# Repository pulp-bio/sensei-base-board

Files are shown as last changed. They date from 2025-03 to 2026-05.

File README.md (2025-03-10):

# SENSEI Base Board

This repository contains the hardware design files for the **SENSEI Base Board**, a flexible and ultra-low-power platform designed for edge AI and signal processing applications. The SENSEI Base Board enables modular integration of external sensors and specialized extension boards, making it an ideal foundation for multi-domain applications and long-term deployments in various monitoring use cases.

## Overview

The **SENSEI Base Board** is designed for advanced edge processing with a focus on low-power operation and flexibility. It incorporates key components such as **GAP9** and **NRF5340**, enabling multi-protocol connectivity and efficient near-sensor computation for advanced feature extraction and data compression. The board is also equipped with a variety of sensor interfaces and external connectors to support a wide range of use cases.

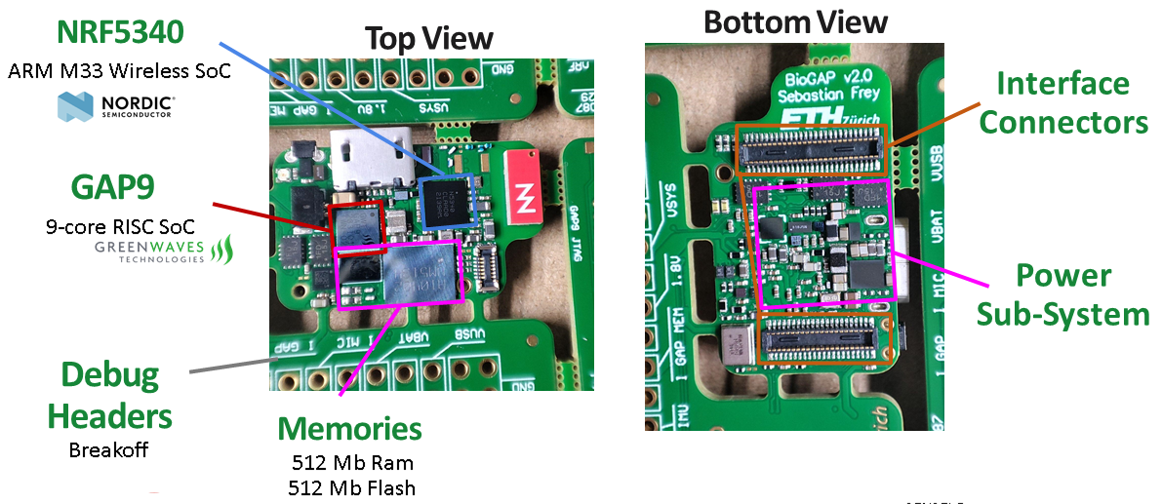
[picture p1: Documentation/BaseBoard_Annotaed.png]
Altium Screenshot


### Key Features
- **GAP9 SoC**:
  - 9-core RISC SoC with a fabric controller running up to 370 MHz.
  - 1536 kB L2 and 128 kB L1 on-chip memories.
  - Hardware acceleration via **NE16**.
  - External RAM (512Mbit) and Flash (512Mbit).
  
- **NRF5340 SoC**:
  - Multi-protocol Bluetooth Low Energy (BLE 5.4), IEEE 802.15.4, ANT, and 2.4GHz proprietary connectivity.
  - Dual-core Arm Cortex-M33 (128/64 MHz application processor and 64 MHz network processor).
  - 1 MB Flash and 512 KB RAM for the application processor, with external memory support.

## Changelog
A detailed changelog is available in the [Changelog.md](Changelog.md) file, which tracks all major updates and revisions to the board's design and documentation.

## Contributors
- **Sebastian Frey** ([sefrey@iis.ee.ethz.ch](mailto:sefrey@iis.ee.ethz.ch))
- **Philip Wiese** ([wiesep@iis.ee.ethz.ch](mailto:wiesep@iis.ee.ethz.ch))

## License
This repository makes use of the following licenses:
- for all *hardware*: Solderpad Hardware License Version 0.51
- for all *images*: Creative Commons Attribution 4.0 International
License][cc-by]

For further information have a look at the license files: `LICENSE.hw`, `LICENSE.images`

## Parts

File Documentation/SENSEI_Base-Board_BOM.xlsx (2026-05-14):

Designator | Comment | Quantity | Manufacturer
C1, C2 | GRM035R60J475ME15D | 2
C3, C4 | CBR02C200F5GAC | 2
C5, C6, C7, C12, C18, C20, C22, C23, C47, C51, C52, C53, C54, C57, C64, C65, C69, C70, C74, C84, C92, C95, C97 | CL03A105KP3NSNC | 23
C8, C10, C24, C49, C55, C71, C72 | C1005X5R0J475K050BC | 7
C9, C11, C19, C21, C25, C26, C27, C28, C29, C30, C31, C33, C34, C35, C36, C37, C38, C39, C48, C50, C56, C58, C60, C61, C73, C75, C76, C77, C78, C79, C80, C81, C82, C85, C86, C88, C89, C90, C94, C96, C98, C99 | GRM033Z71C104KE14D | 42
C13, C14 | GRM033R61A225KE47D | 2
C15, C16, C17, C40, C41, C42, C43 | CL05A226MQ5QUNC | 7
C32, C44, C59, C83, C87 | CL05A106MP5NUNC | 5 | Samsung
C46 | GRM033R71E332KA12D | 1
C62, C63 | GRM0335C1H111JA01D | 2
C66 | GRM033R71C222KA88D | 1
C67 | GJM0335C1ER70BB01D | 1
C91 | GRM21BR60G107ME11L | 1
D1 | SML-LX0404SIUPGUSB | 1 | Lumex
D2, D3 | TPD1E01B04DPYRQ1 | 2
D4 | NSR20F30NXT5G | 1 | On Semiconductor
E1 | NN03-320 | 1 | Fractus Antennas
GAP1 | GAP9_MC | 1
IC1 | MAX38643AENT+T | 1
IC2 | TS5A3153YZPR | 1
IC3 | TS5A3167YZPR | 1
J1 | USB3076-30-A | 1
J2 | DF40C-50DP-0.4V(51) | 1
J3, J7 | 3220-10-0100-00 | 2
J4 | DF40C-40DP-0.4V(51) | 1
J5 | 505066-1222 | 1
J8 | DF52-2S-0.8H(21) | 1
L1 | DFE18SAN1R0ME0L | 1
L2 | DFE201210S-1R5M=P2 | 1 | Murata
L3, L10 | LQM18DN100M70L | 2
L4, L5 | LQP03HQ2N2B02D | 2
L6 | LQW15AN1N6C80D | 1
L7 | DFE201610E-4R7M=P2 | 1
L8 | LQW18AN4N2G80D | 1
L9 | LQW18AN7N5G80D | 1
MIC1 | MMICT5838-00-012 | 1
R1, R3, R5, R8, R10 | CRCW04021R00FKEDHP | 5 | Vishay Dale
R2 | CRCW020120K0FKED | 1 | Vishay Dale
R4, R36, R37, R38, R40, R42, R43, R49, R50 | CRCW0201220RFKED | 9 | Vishay Dale
R6, R7, R22 | RC0201FR-07100KL | 3
R9, R24, R26, R27, R28, R29, R31 | RMCF0201FT10K0 | 7
R11, R12, R13, R17, R32 | ERJ-1GNJ105C | 5
R14, R15 | RR0510P-104-D | 2
R19, R20 | ERJ-1GNF4990C | 2 | Panasonic
R23 | RMCF0201ZT0R00 | 1
R25 | RC0201FR-072R2L | 1
R33, R34 | RMCF0402ZT0R00 | 2
R35, R44, R45, R46, R47, R48 | CRCW020149R9FNED | 6 | Vishay Dale
R39 | RK73B1JTTD562J | 1 | KOA Speer
RT1 | ERT-JZEG103FA | 1
S1 | NanoT160BP | 1
SW3, SW4 | PTS815 SJM 250 SMTR LFS | 2
U1 | MX25UM51345GBEI00 | 1
U2 | APS512XXN-OB9-WB | 1
U3 | MAX77654BENV+T | 1 | Maxim
U4, U6, U7, U8, U18, U20 | TPS22916CYFPR | 6
U5 | NRF5340-CLAA-R7 | 1 | Nordic
U9, U10, U11, U12, U13 | TMUX1112RSVR | 5 | Texas Instruments
U15 | IS31FL3194-CLS2-TR | 1 | ISSI
U16 | 74AUP1G32GX,125 | 1
U17 | APS12804O-SQRH-WA | 1
U19 | PESD1USB30Z | 1 | NXP Semiconductors
U21 | LSM6DSV16BXTR | 1
Y2 | ECS-240-10-47Q-CES-TR | 1
Y3 | ECS-320-7-48B-JTM-TR5 | 1 | ECS International
Y4 | ECS-.327-9-1210-TR | 1

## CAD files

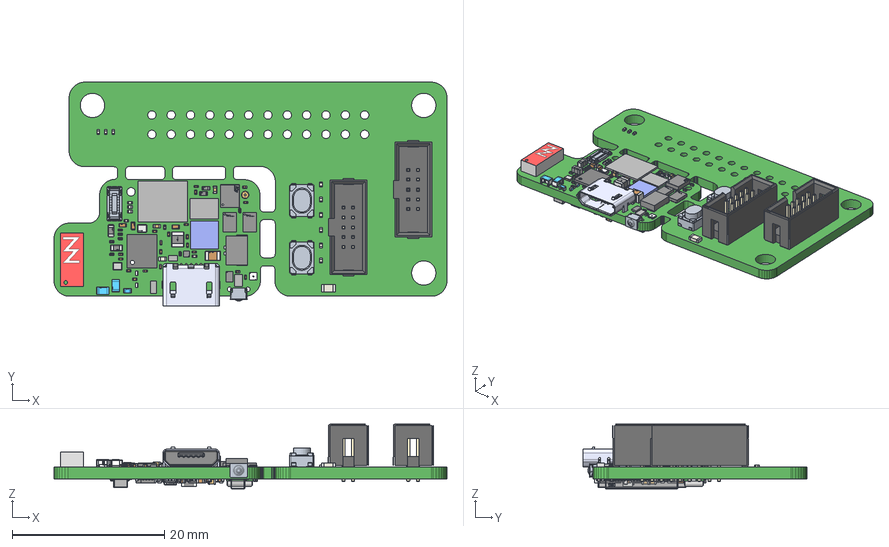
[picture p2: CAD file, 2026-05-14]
Documentation/SENSEI_Base-Board_3D_step.step
51.6 x 29.4 x 8.47 mm
STM Logo, Yury, Abjustable
Murata Logo 3 x 5
USB3076-30-A--3DModel-STEP-56544
Extruded x 105
Linear Pattern 01 x 2
Pins:1 x 2
Murata Logo x 2
Terminals x 3
center x 2
Murata x 4
Murata_1 x 3
side x 48
Samsung logo x 23
ECS-240-10-47Q-CES-TR--3DModel-STEP-269445
terminals x 69
logo x 69
Pins x 10
Res_Stackpole_RMCF0402FT1K07_eec x 10
SOT1226-3 Leads
SOT1226-3 Body
A1
A2
B1
C1
C2
T5838
Samsung Logo Yury adjustable x 5
DF40C-50DP_RGB8421504
NANOT160BP_PART1
top x 9
PTS815SJM250SMTRLFS_PART3 x 2
PTS815SJM250SMTRLFS_PART2 x 2
PTS815SJM250SMTRLFS_PART1 x 2
solidBody
solidTerminal
Base
Led
R
G
B
Pads
Polarity
Anode mark
Lumex Logo
Center
ball x 132
PIN1 dot x 5
TI_Logo_1mm x 5
NN03-320(2)^Assem1
Hirose Electric
21-100307_N302C21_MXM
Susumu Logo adjustable x 2
FER 0805
Logo x 2
Y_ECX-1048
Ind_Murata_LQP03HQ0N5B02D_eec x 12

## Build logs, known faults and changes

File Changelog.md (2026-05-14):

# Changelog

## [1.1] (14.05.2026)

### Added

- Debugging connector for nRF5340.
- Integration of a new IMU (LSM6DSV16BX) with accelerometer, gyroscope, QVAR, AI features, and hearable-oriented functions (e.g., bone-conduction-related sensing).

### Changed

- Antenna trace and matching circuit optimized.
- Increased component spacing of various passives for better assembly.

## [1.0] (10.03.2025)
- Inital version

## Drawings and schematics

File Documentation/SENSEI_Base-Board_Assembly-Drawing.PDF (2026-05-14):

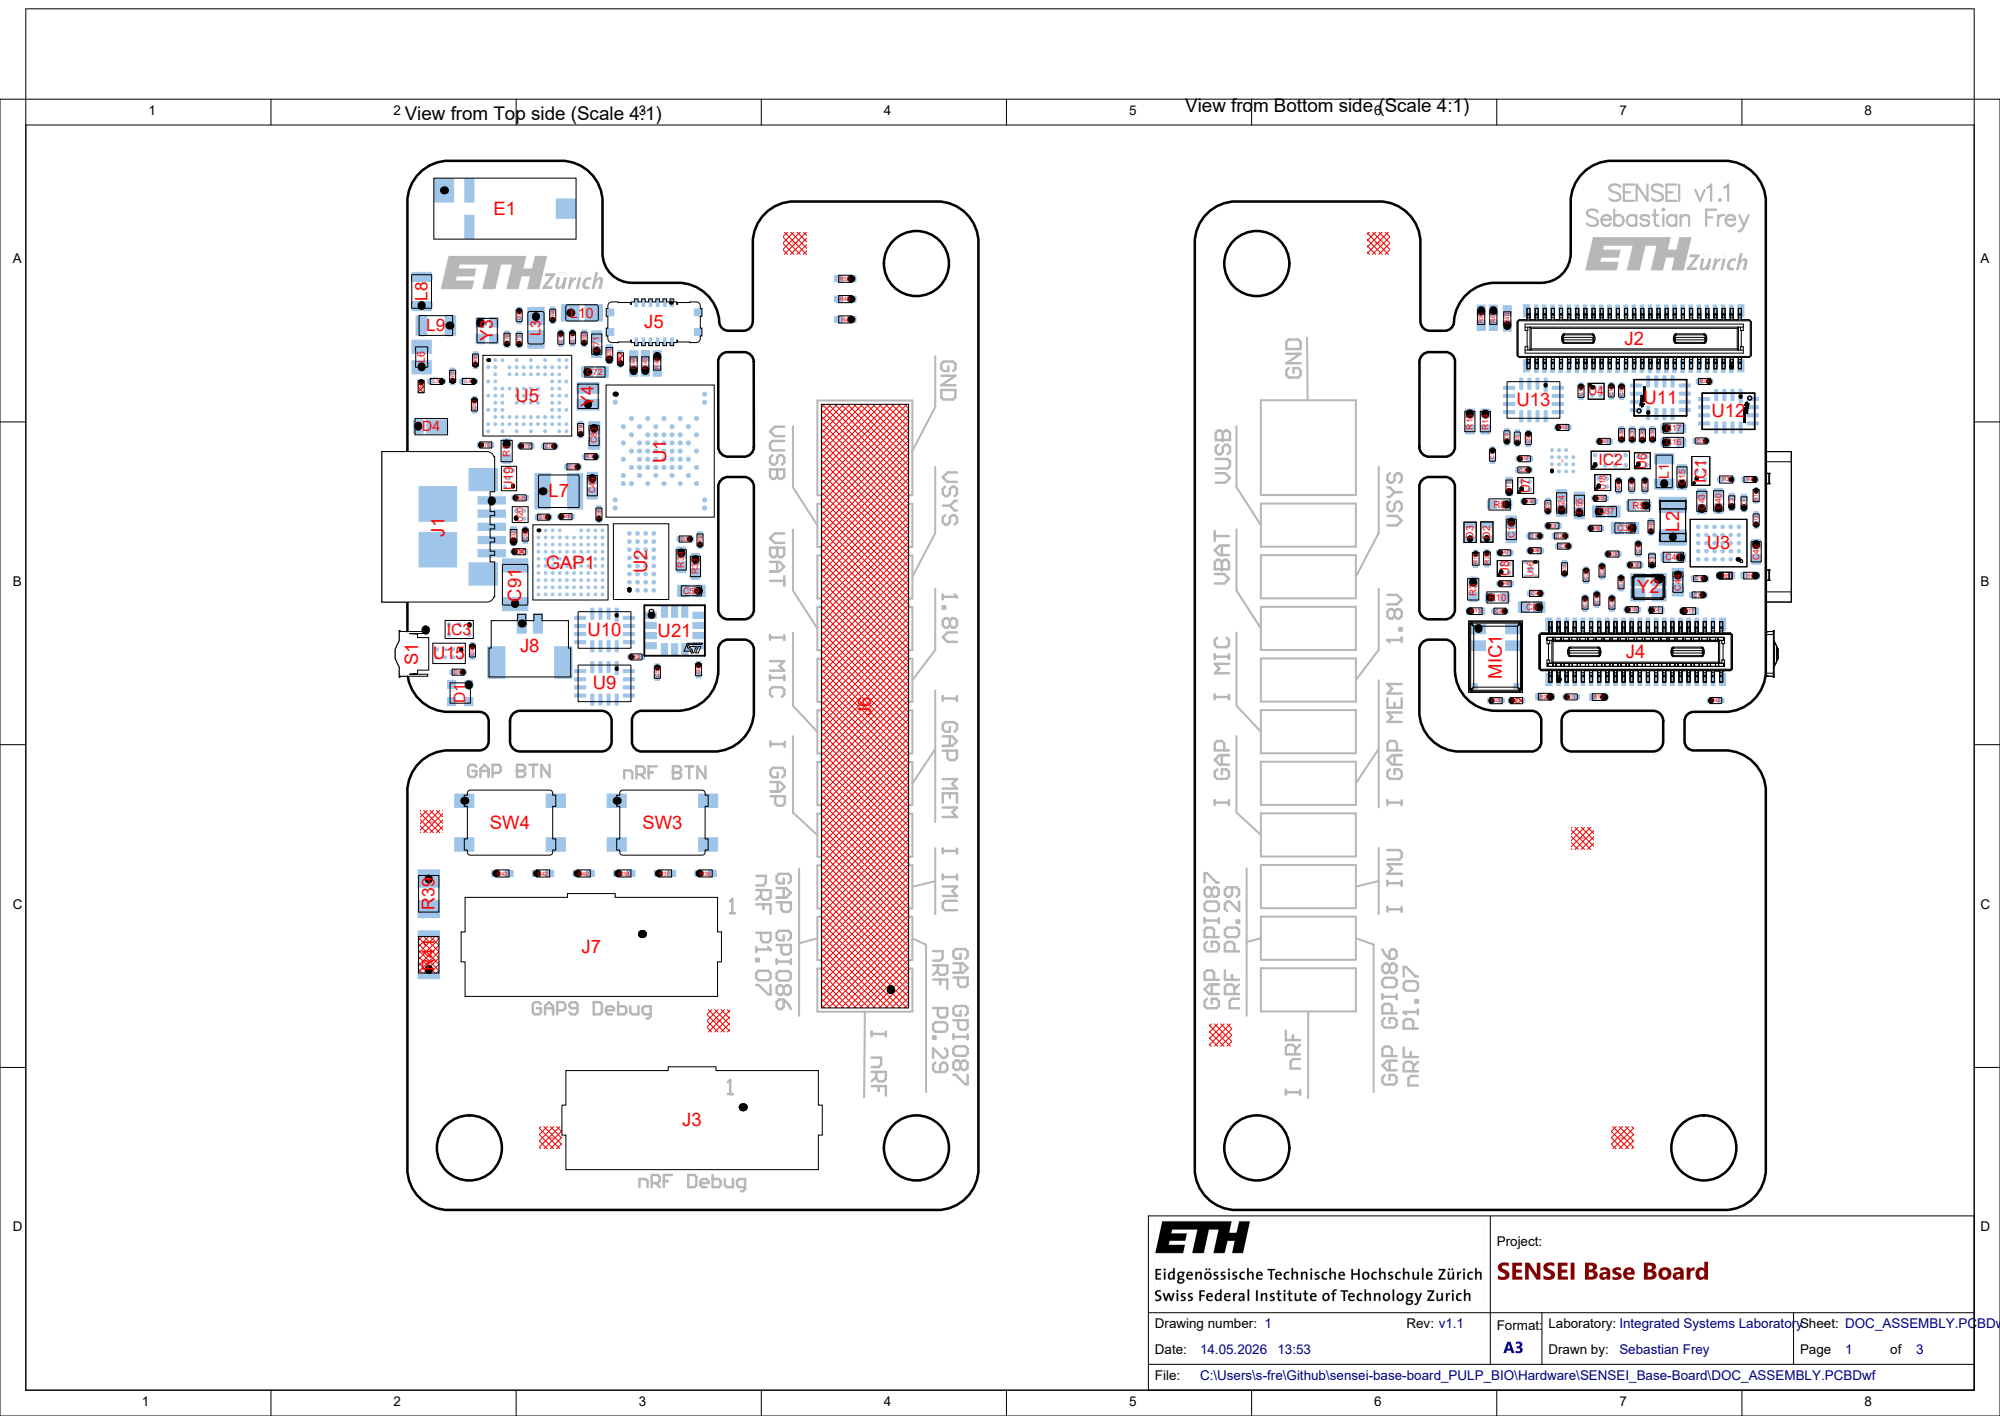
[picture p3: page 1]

View from Top side (Scale 4:1)

View from Bottom side (Scale 4:1)

Laboratory: Integrated Systems Laboratory
Drawn by:

C:\Users\s-fre\Github\sensei-base-board_PULP_BIO\Hardware\SENSEI_Base-Board\DOC_ASSEMBLY.PCBDwf

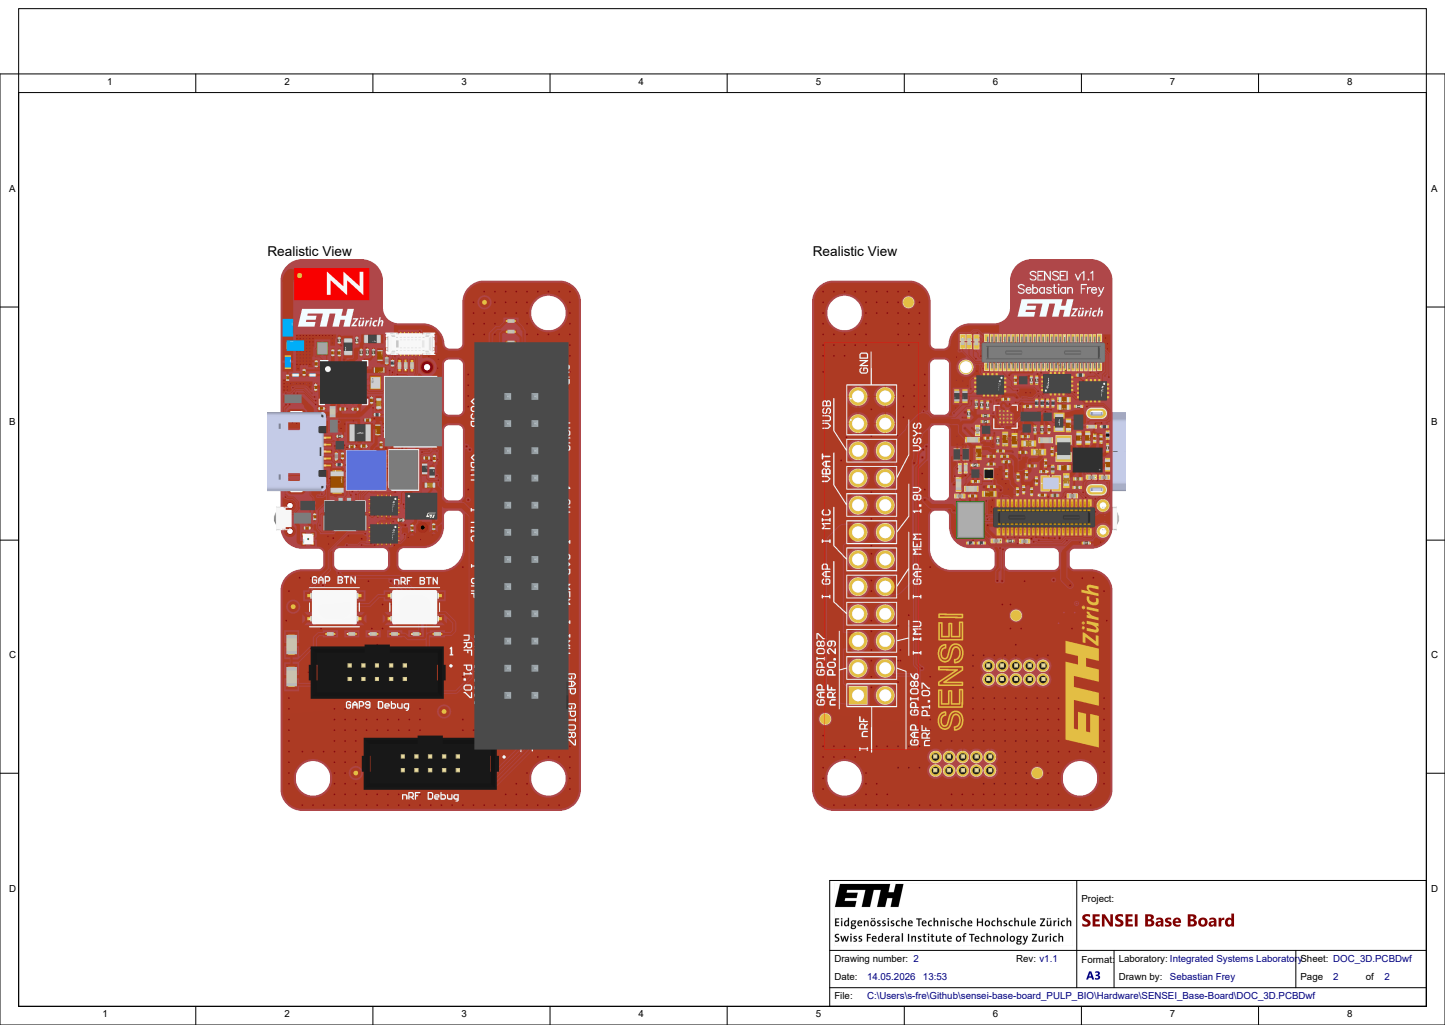
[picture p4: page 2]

Project:

Drawing number: 2 Rev: v1.1 Date: 14.05.2026 13:53 | Format: | Laboratory: Integrated Systems Laboratory Drawn by: Sebastian Frey | Sheet: DOC_3D.PCBDwf

C:\Users\s-fre\Github\sensei-base-board_PULP_BIO\Hardware\SENSEI_Base-Board\DOC_3D.PCBDwf

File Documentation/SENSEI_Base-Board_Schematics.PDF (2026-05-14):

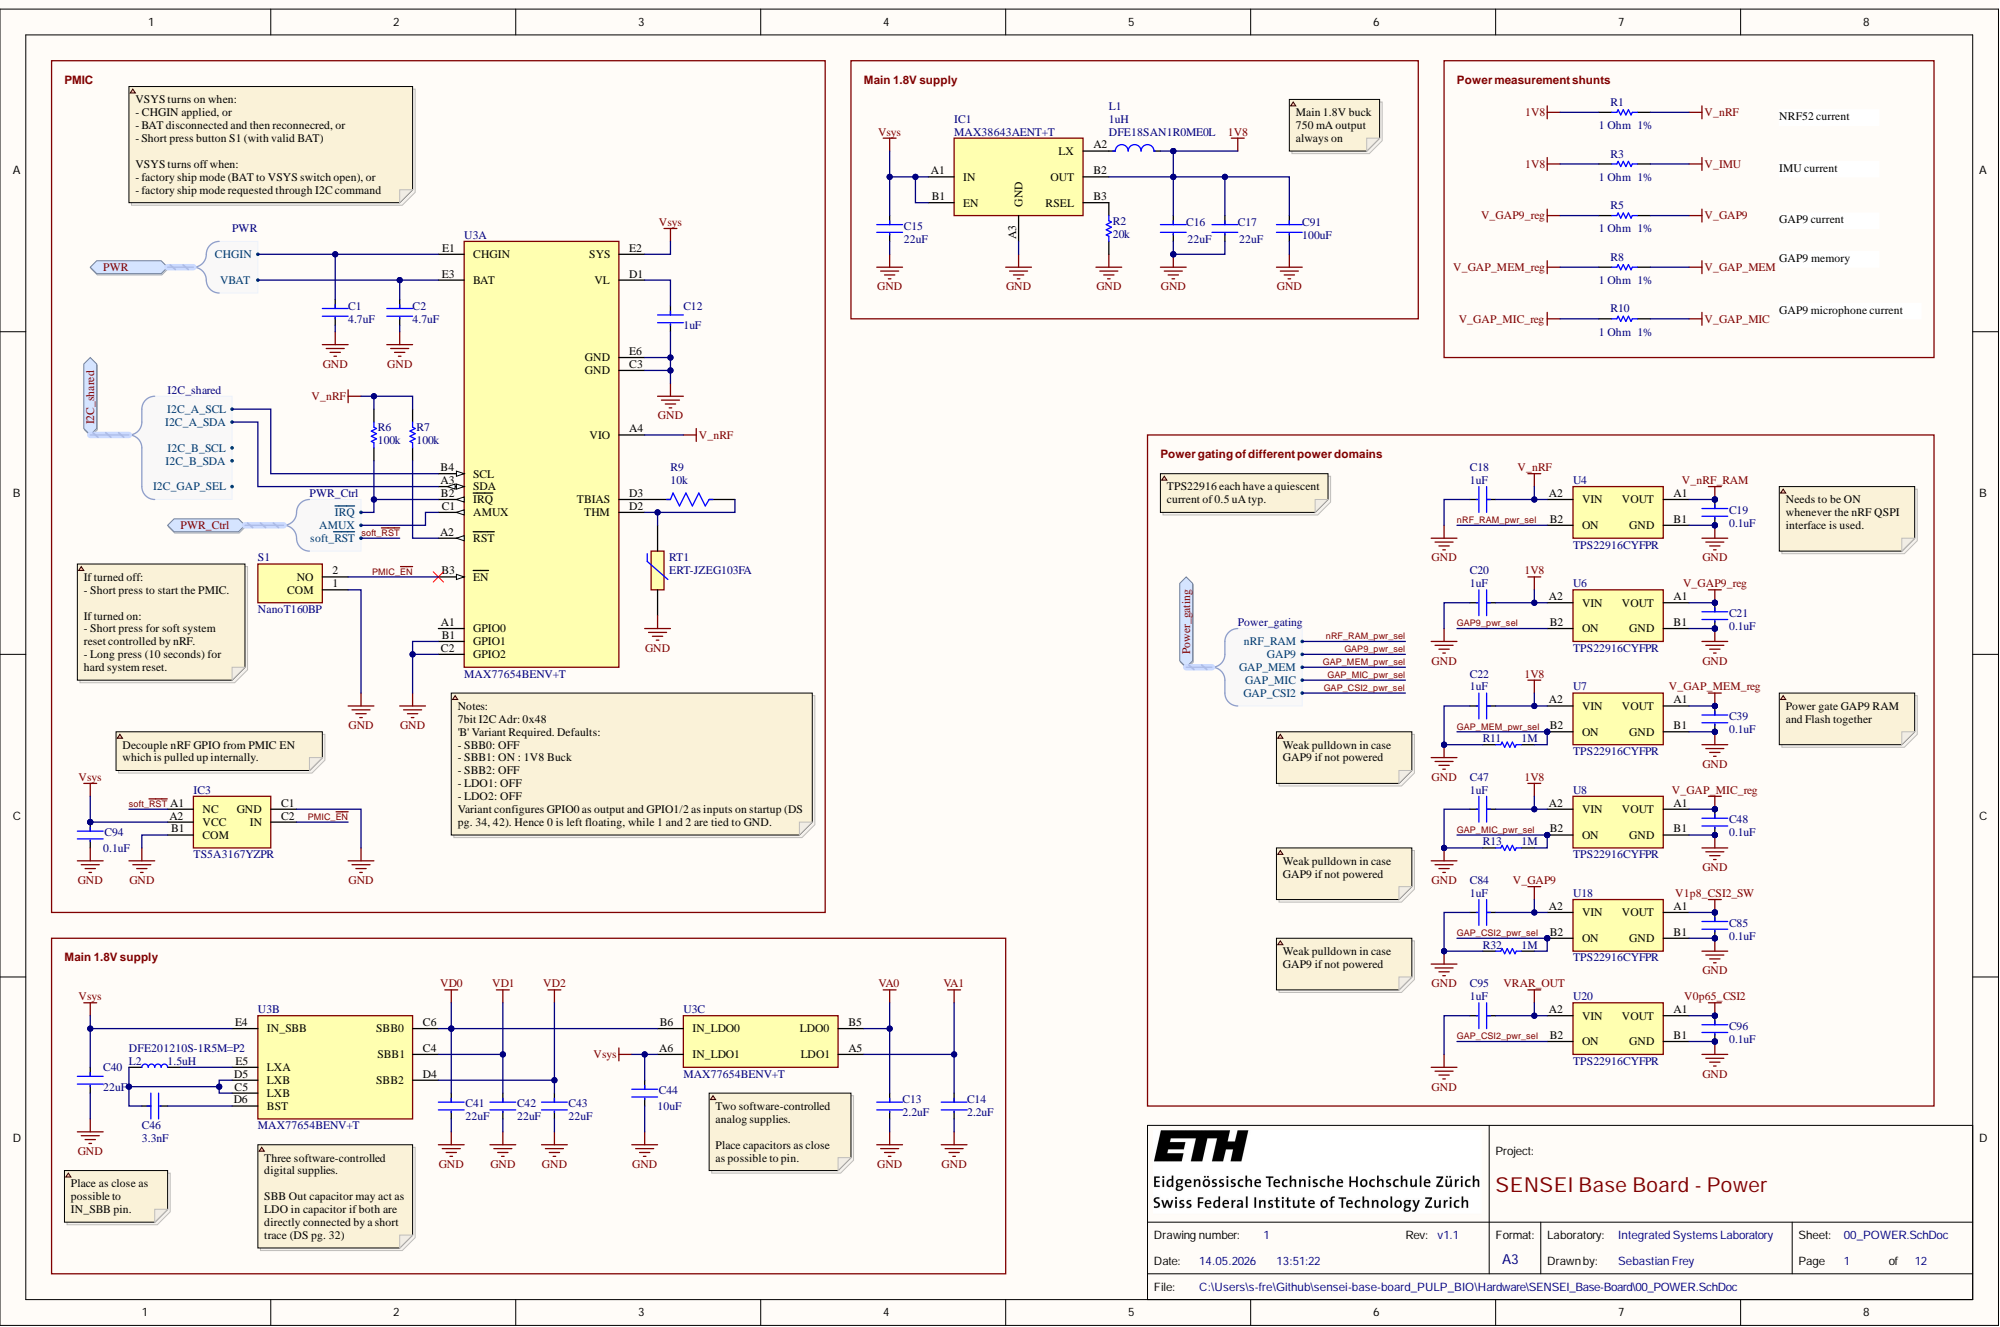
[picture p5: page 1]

Proje c t: S E N S E I B a s e B o a r d -P o we r

Drawing num b e r: 1 R e v : v 1 . 1 D a te : 14.05. 2 02 6 13:51 : 2 2 | For m a t: A 3 | Laborato ry : Integrated Sy s tem s Labo ra to ry Drawn by : Sebas tian F re y | Shee t: 00_POW E R . S c h D o c Pag e 1 o f 1 2

\s-fre\Github\sensei-base-board_PULP_BIO\Hard
sers

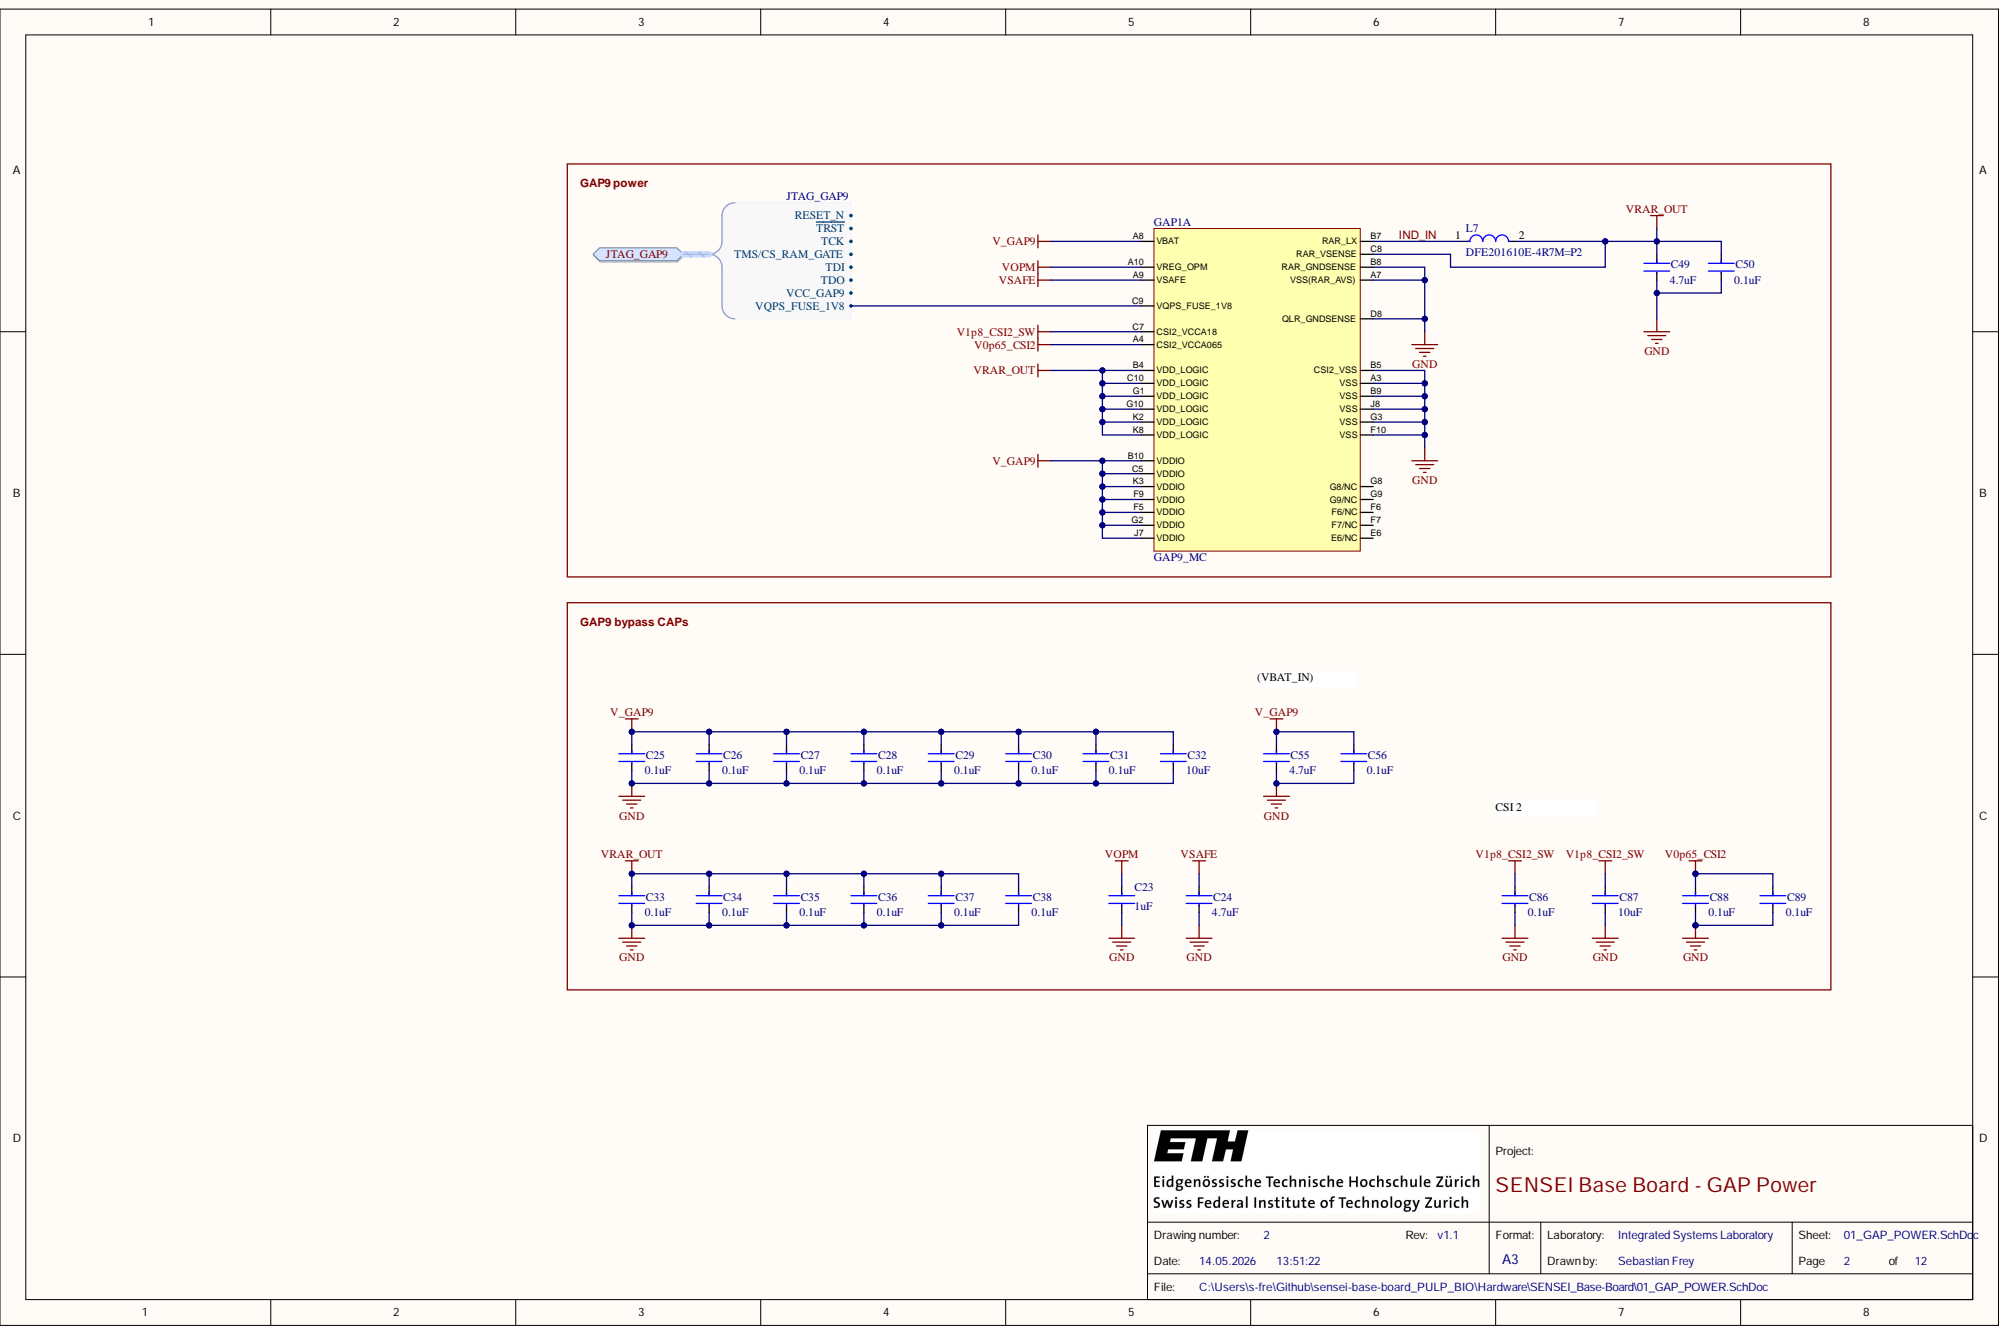
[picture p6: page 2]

VDD_LOGIC G1

VDD_LOGIC K2

VDDIO C5
VDDIO K3
VDDIO F5 VDDIO F9

VDDIO G2

Project: SENSEI Base Board - GAP Power

Drawing number: 2 Rev: v1.1 Date: 14.05.2026 13:51:22 | Format: A3 | Laboratory: Integrated Systems Laboratory Drawn by: Sebastian Frey | Sheet: 01_GAP_POWER.SchDoc Page 2 of 12

C:\Users\s-fre\Github\sensei-base-board_PULP_BIO\Hardware\SENSEI_Base-Board\01_GAP_POWER.SchDoc

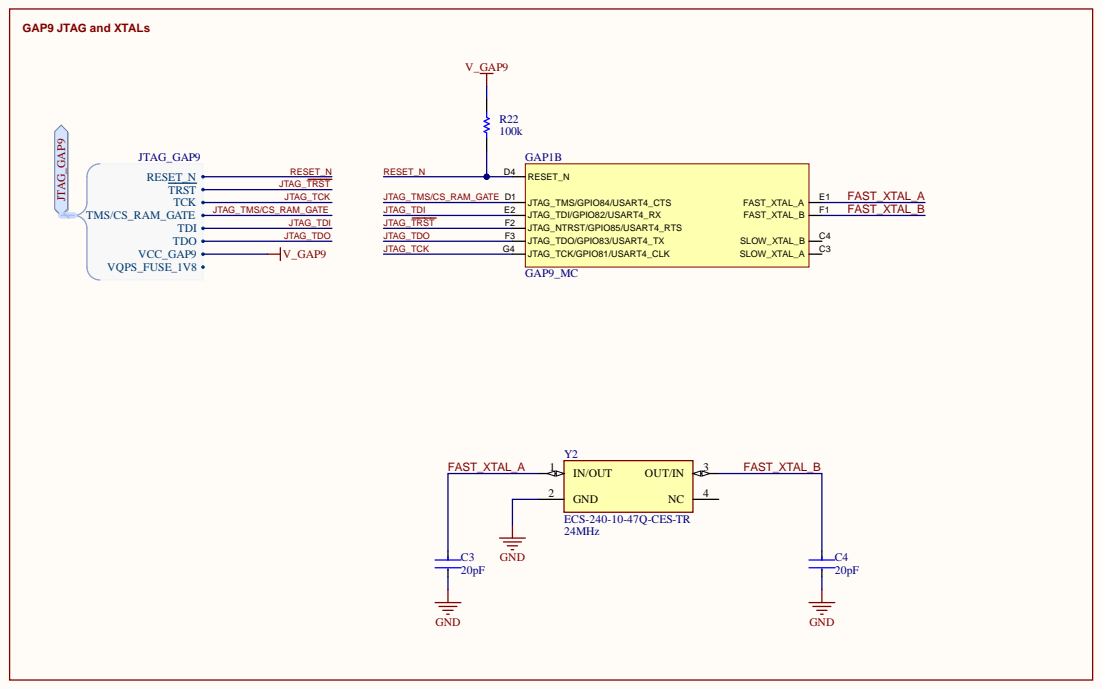
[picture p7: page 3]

Project: SENSEI Base Board - GAP JTAG & XTAL

Page 3 of 12

C:\Users\s-fre\Github\sensei-base-board_PULP_BIO\Hardware\SENSEI_Base-Board\02_GAP_JTAG_XTALs.SchDoc

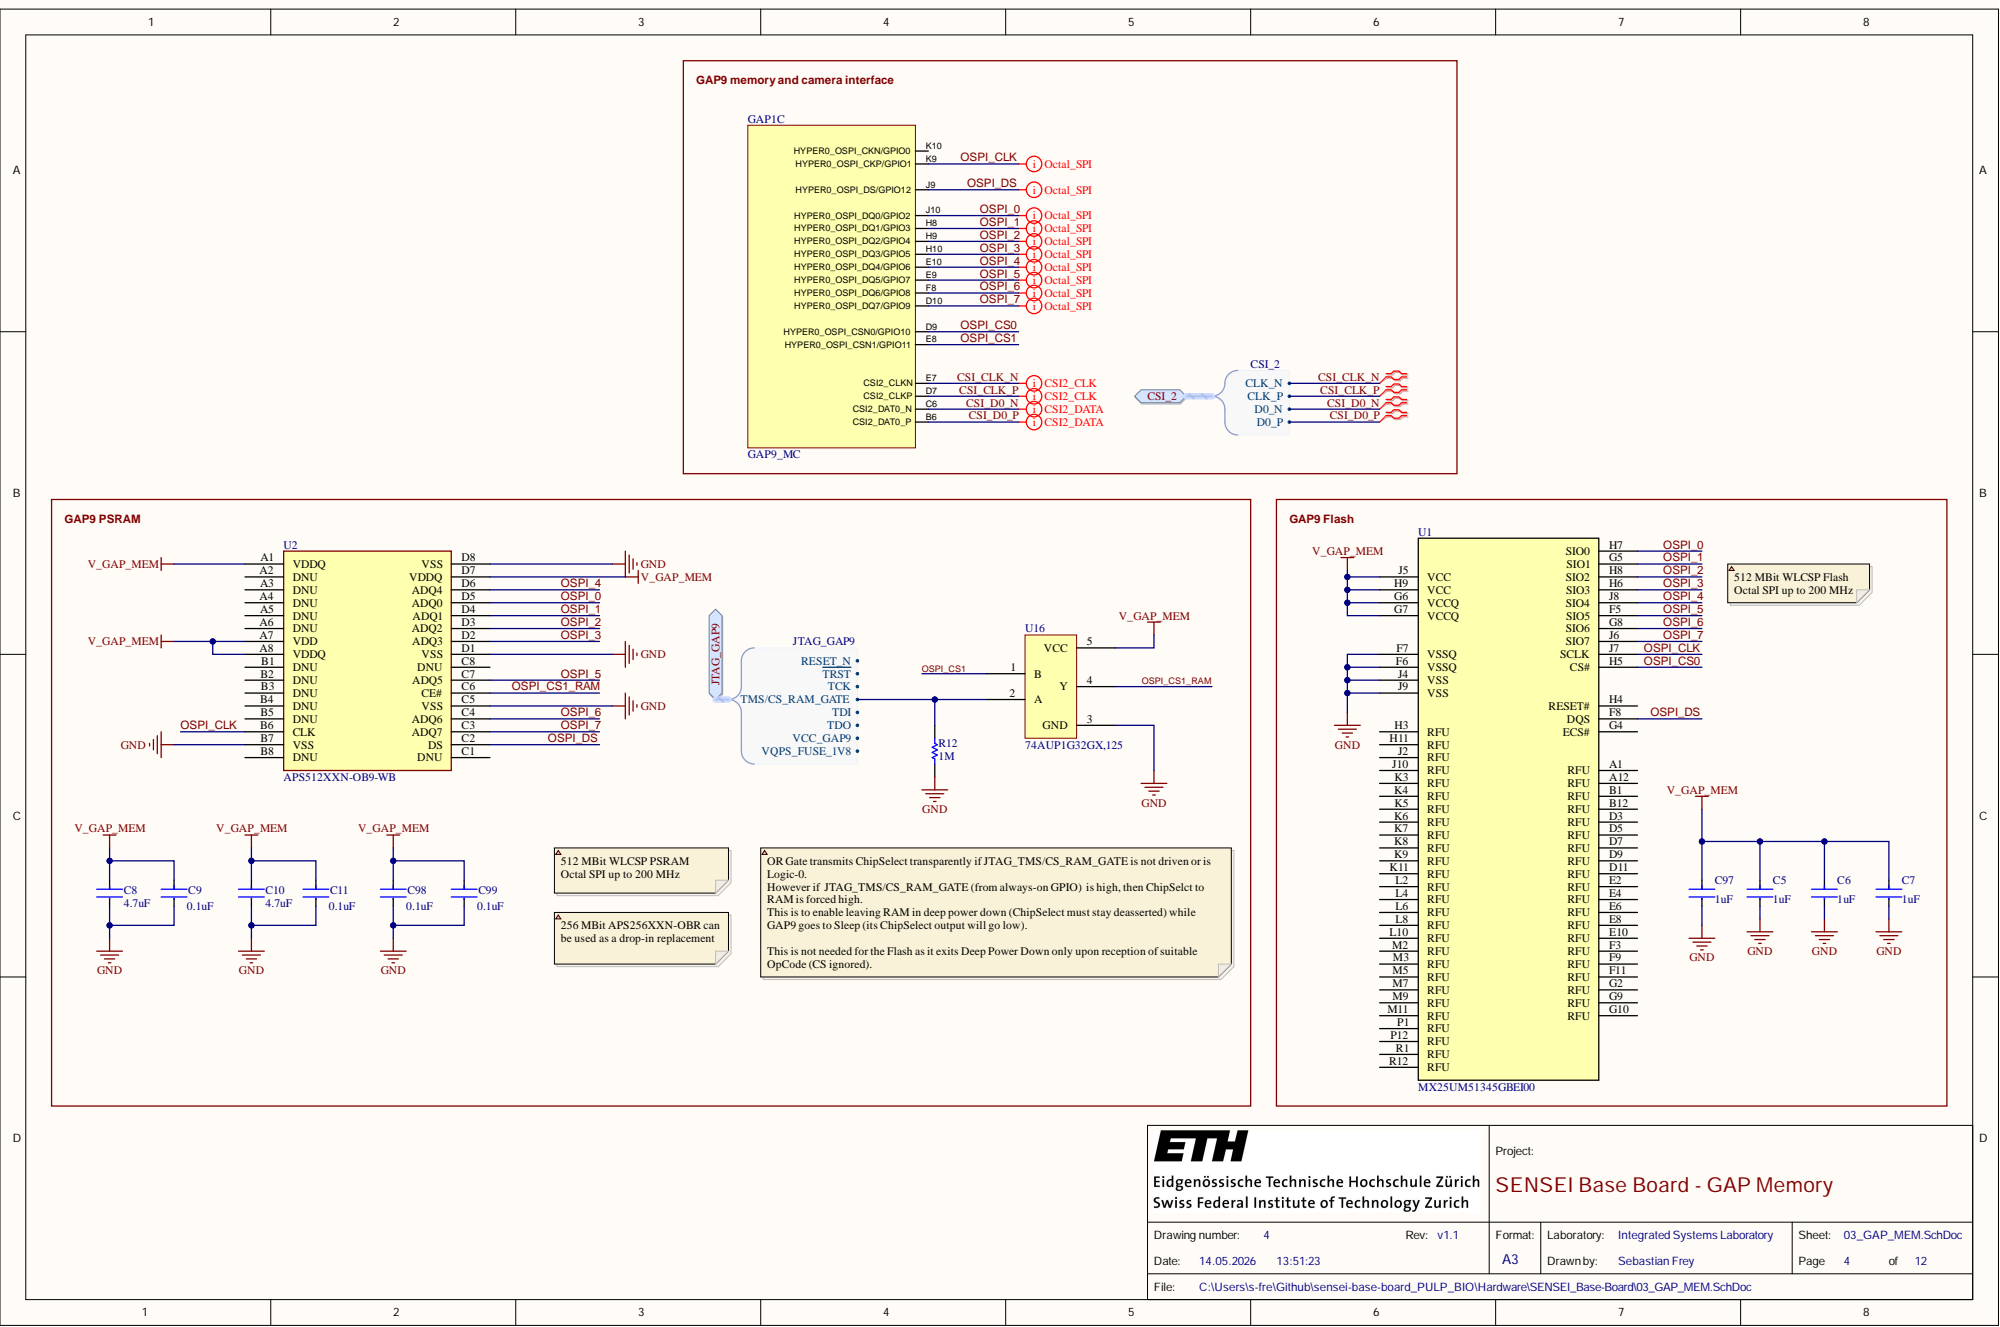
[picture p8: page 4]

Proje c t: S E N S E I B a s e B o a r d -G A P M e m o ry

Drawing num b e r: 4 R e v : v 1 . 1 D a te : 14.05. 2 02 6 13:51 : 2 3 | For m a t: A 3 | Laborato ry : Integrated Sy s tem s Labo ra to ry Drawn by : Sebas tian F re y | Shee t: 03_GAP_M E M . S c h D o c Pag e 4 o f 1 2

\s-fre\Github\sensei-base-board_PULP_BIO\Hardwa
sers

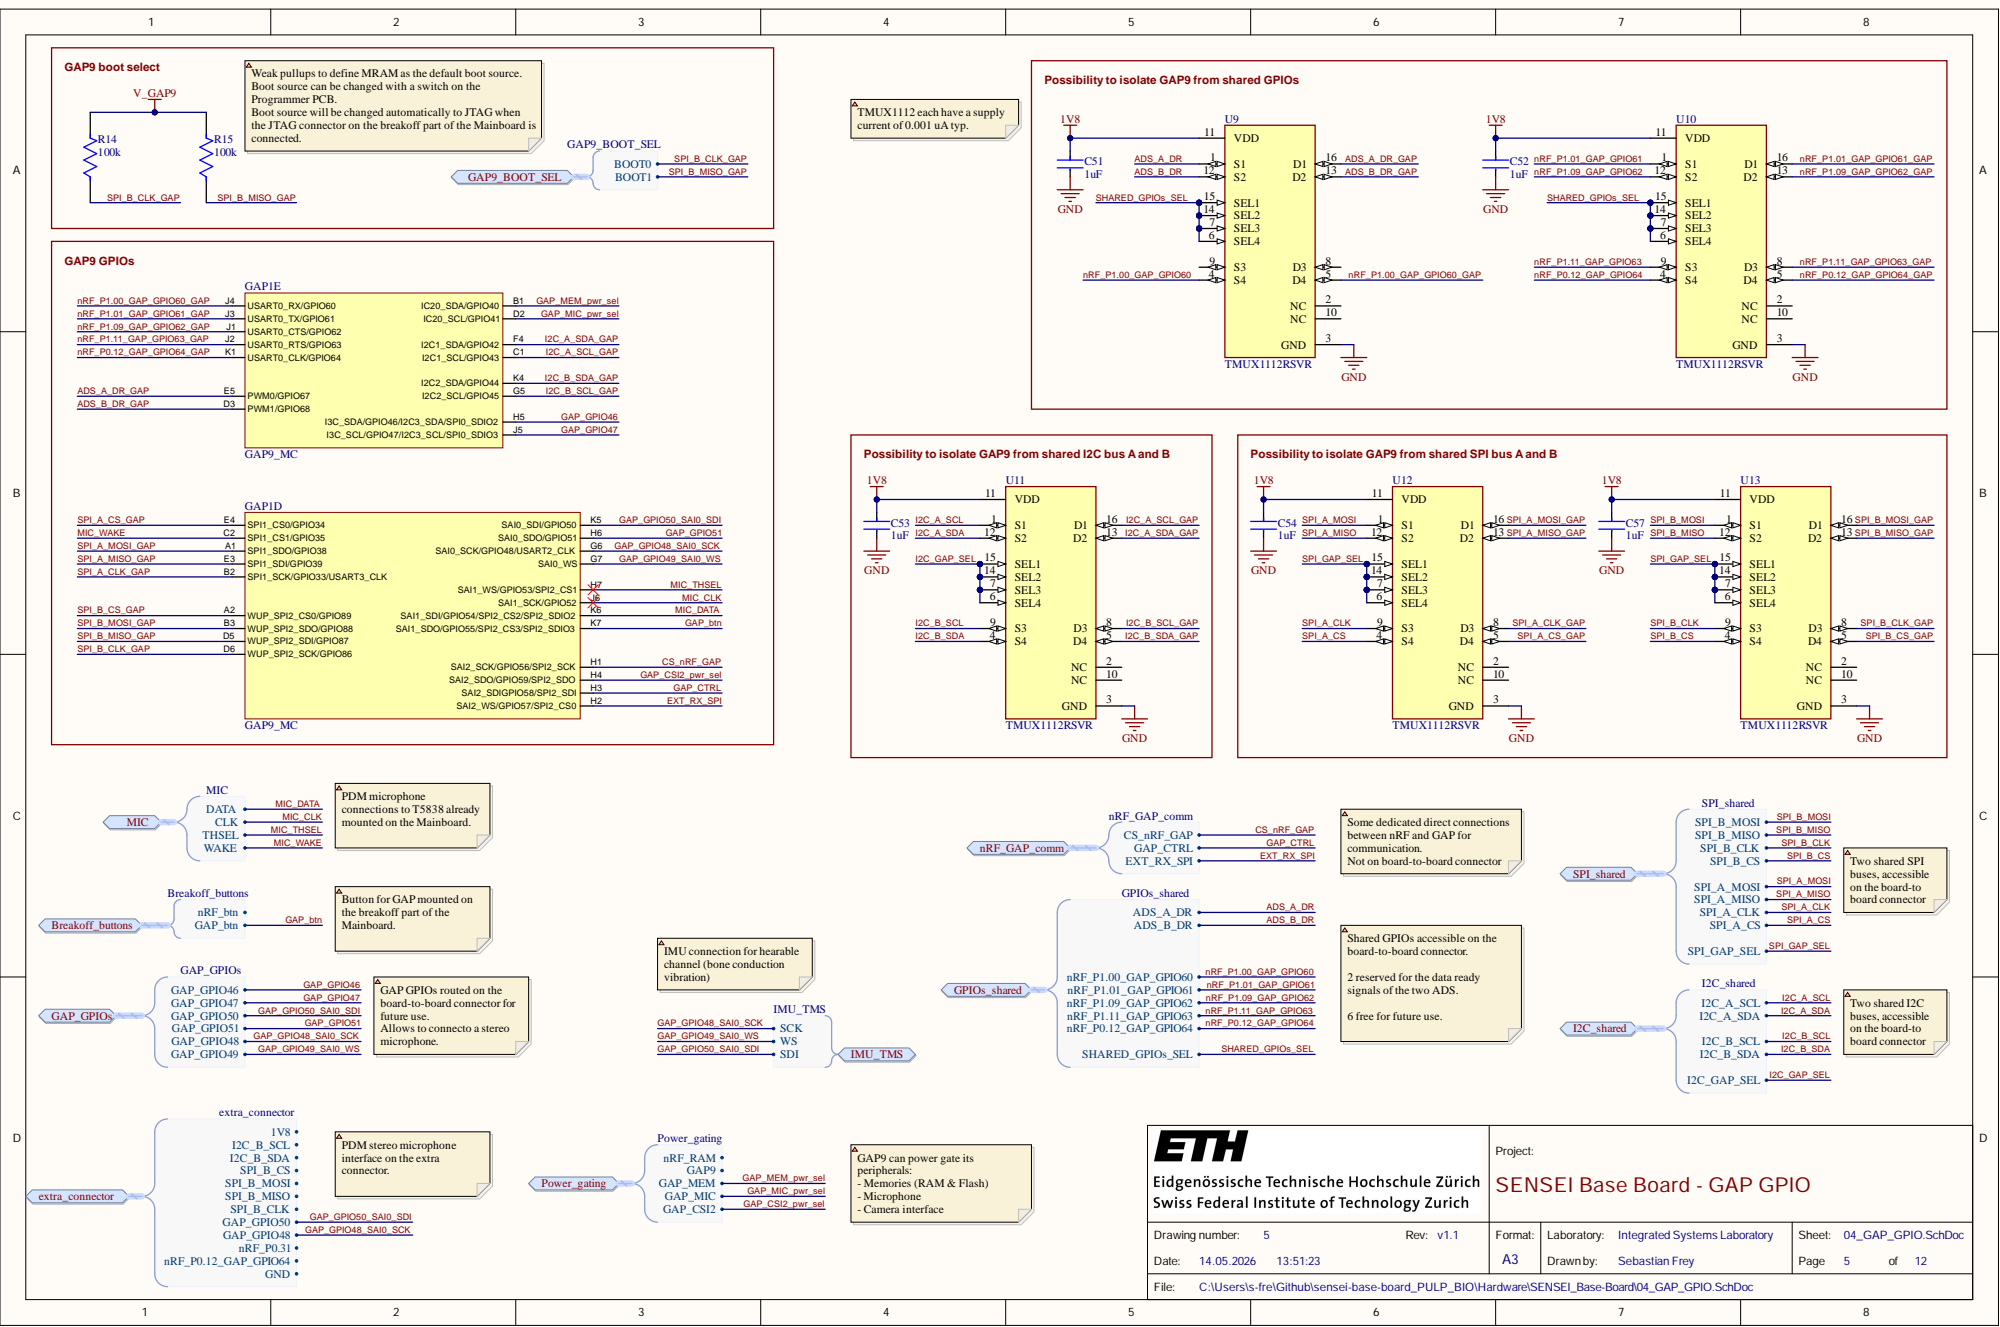
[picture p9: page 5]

Weak pullups to define MRAM as the default boot source.
Boot source can be changed with a switch on the
Programmer PCB.
Boot source will be changed automatically to JTAG when
the JTAG connector on the breakoff part of the Mainboard is
connected.

Possibility to isolate GAP9 from shared GPIOs

TMUX1112 each have a supply
current of 0.001 uA typ.

PDM microphone
connections to T5838 already
mounted on the Mainboard.

Some dedicated direct connections
between nRF and GAP for
communication.
Not on board-to-board connector

Two shared SPI
buses, accessible
on the board-to
board connector

Button for GAPmounted on
the breakoff part of the
Mainboard.

IMU connection for hearable
channel (bone conduction
vibration)

Shared GPIOs accessible on the
board-to-board connector.

2 reserved for the data ready
signals of the two ADS.

GAP GPIOs routed on the
board-to-board connector for
future use.
Allows to connecto a stereo
microphone.

Two shared I2C

6 free for future use.

PDM stereo microphone
interface on the extra
connector.

Project: SENSEI Base Board - GAP GPIO

GAP9 can power gate its
peripherals:
- Memories (RAM & Flash)
- Microphone
- Camera interface

04_GAP_GPIO.SchDoc Page 5 of 12

C:\Users\s-fre\Github\sensei-base-board_PULP_BIO\Hardware\SENSEI_Base-Board\04_GAP_GPIO.SchDoc

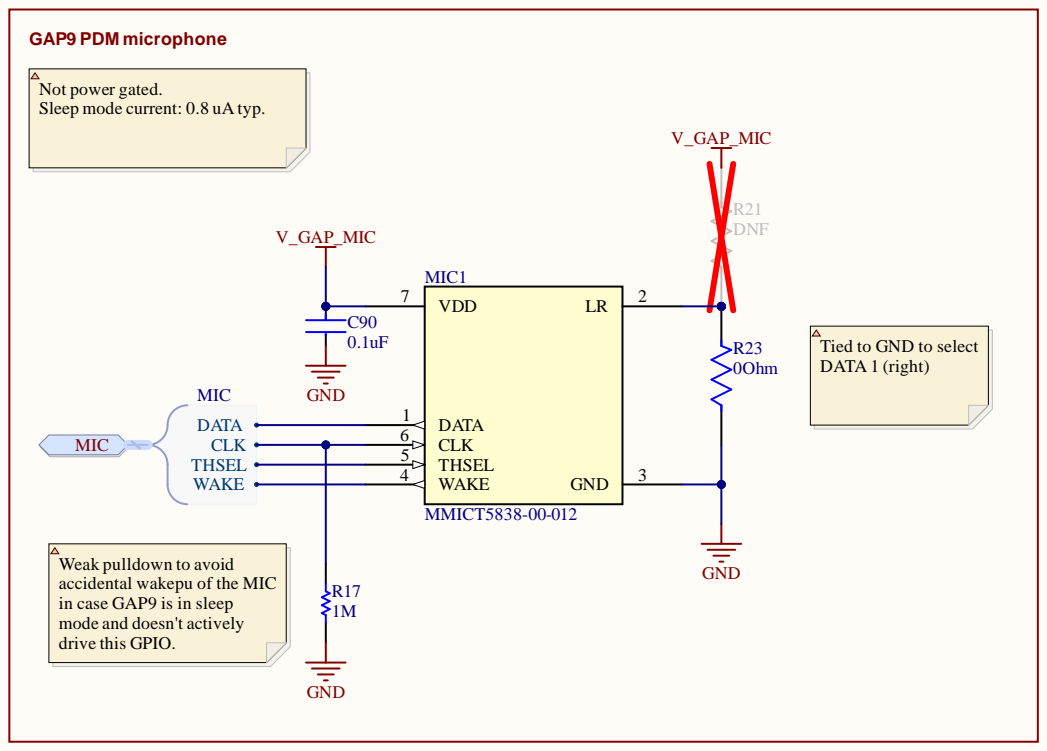
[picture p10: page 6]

Proje c t: S E N S E I B a s e B o a r d -G A P M I C

Drawing num b e r: 6 R e v : v 1 . 1 D a te : 14.05. 2 02 6 13:51 : 2 3 | For m a t: A 3 | Laborato ry : Integrated Sy s tem s Labo ra to ry Drawn by : Sebas tian F re y | Shee t: 05_GAP_M I C . S c h D o c Pag e 6 o f 1 2

\s-fre\Github\sensei-base-board_PULP_BIO\Hard
sers

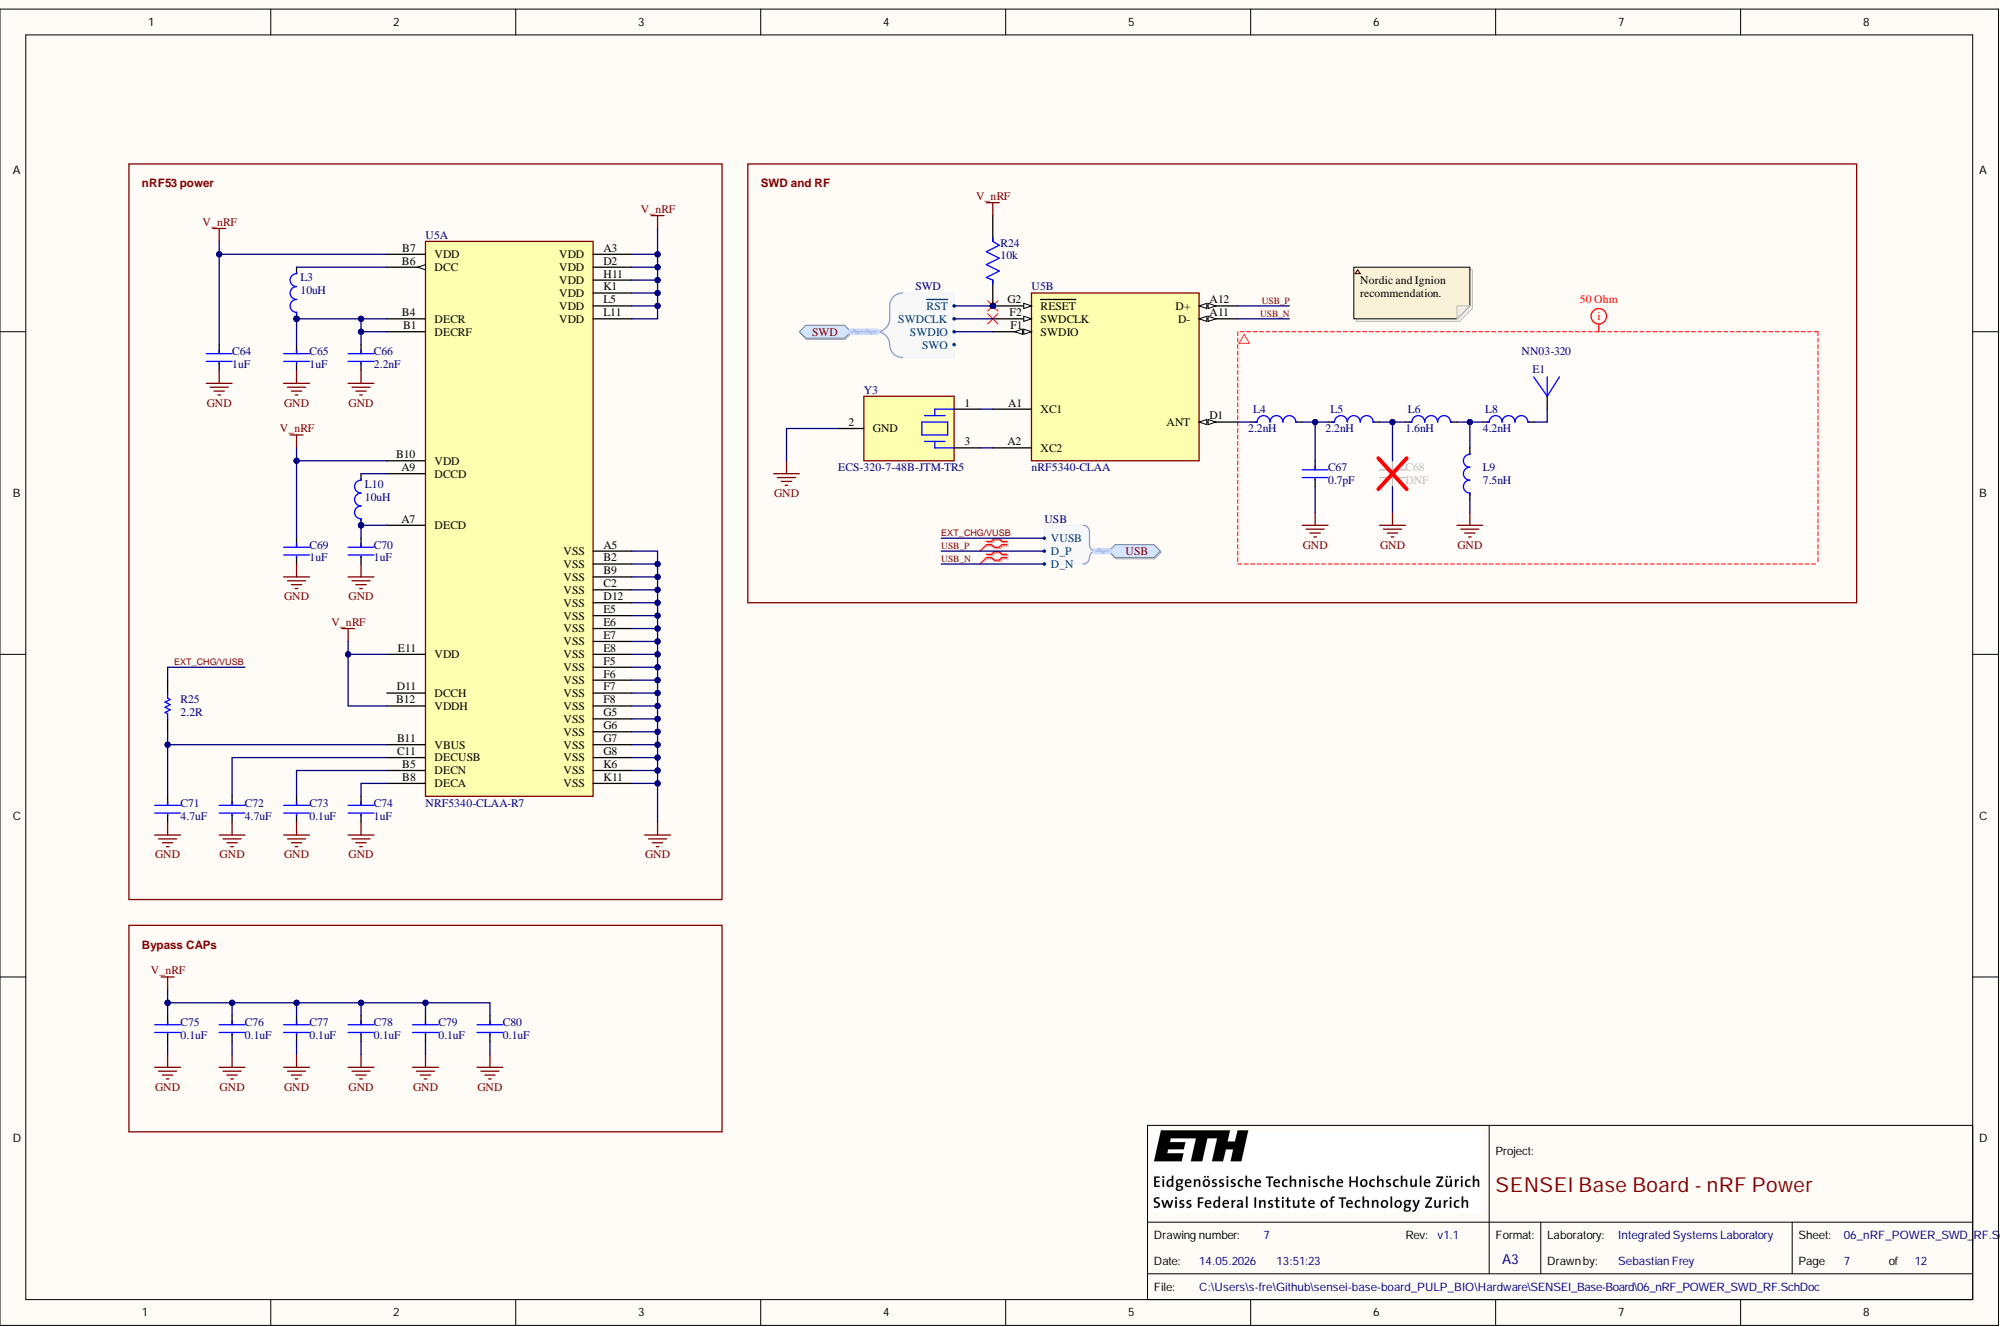
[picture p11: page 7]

Project: SENSEI Base Board - nRF Power

Page 7 of 12

C:\Users\s-fre\Github\sensei-base-board_PULP_BIO\Hardware\SENSEI_Base-Board\06_nRF_POWER_SWD_RF.SchDoc

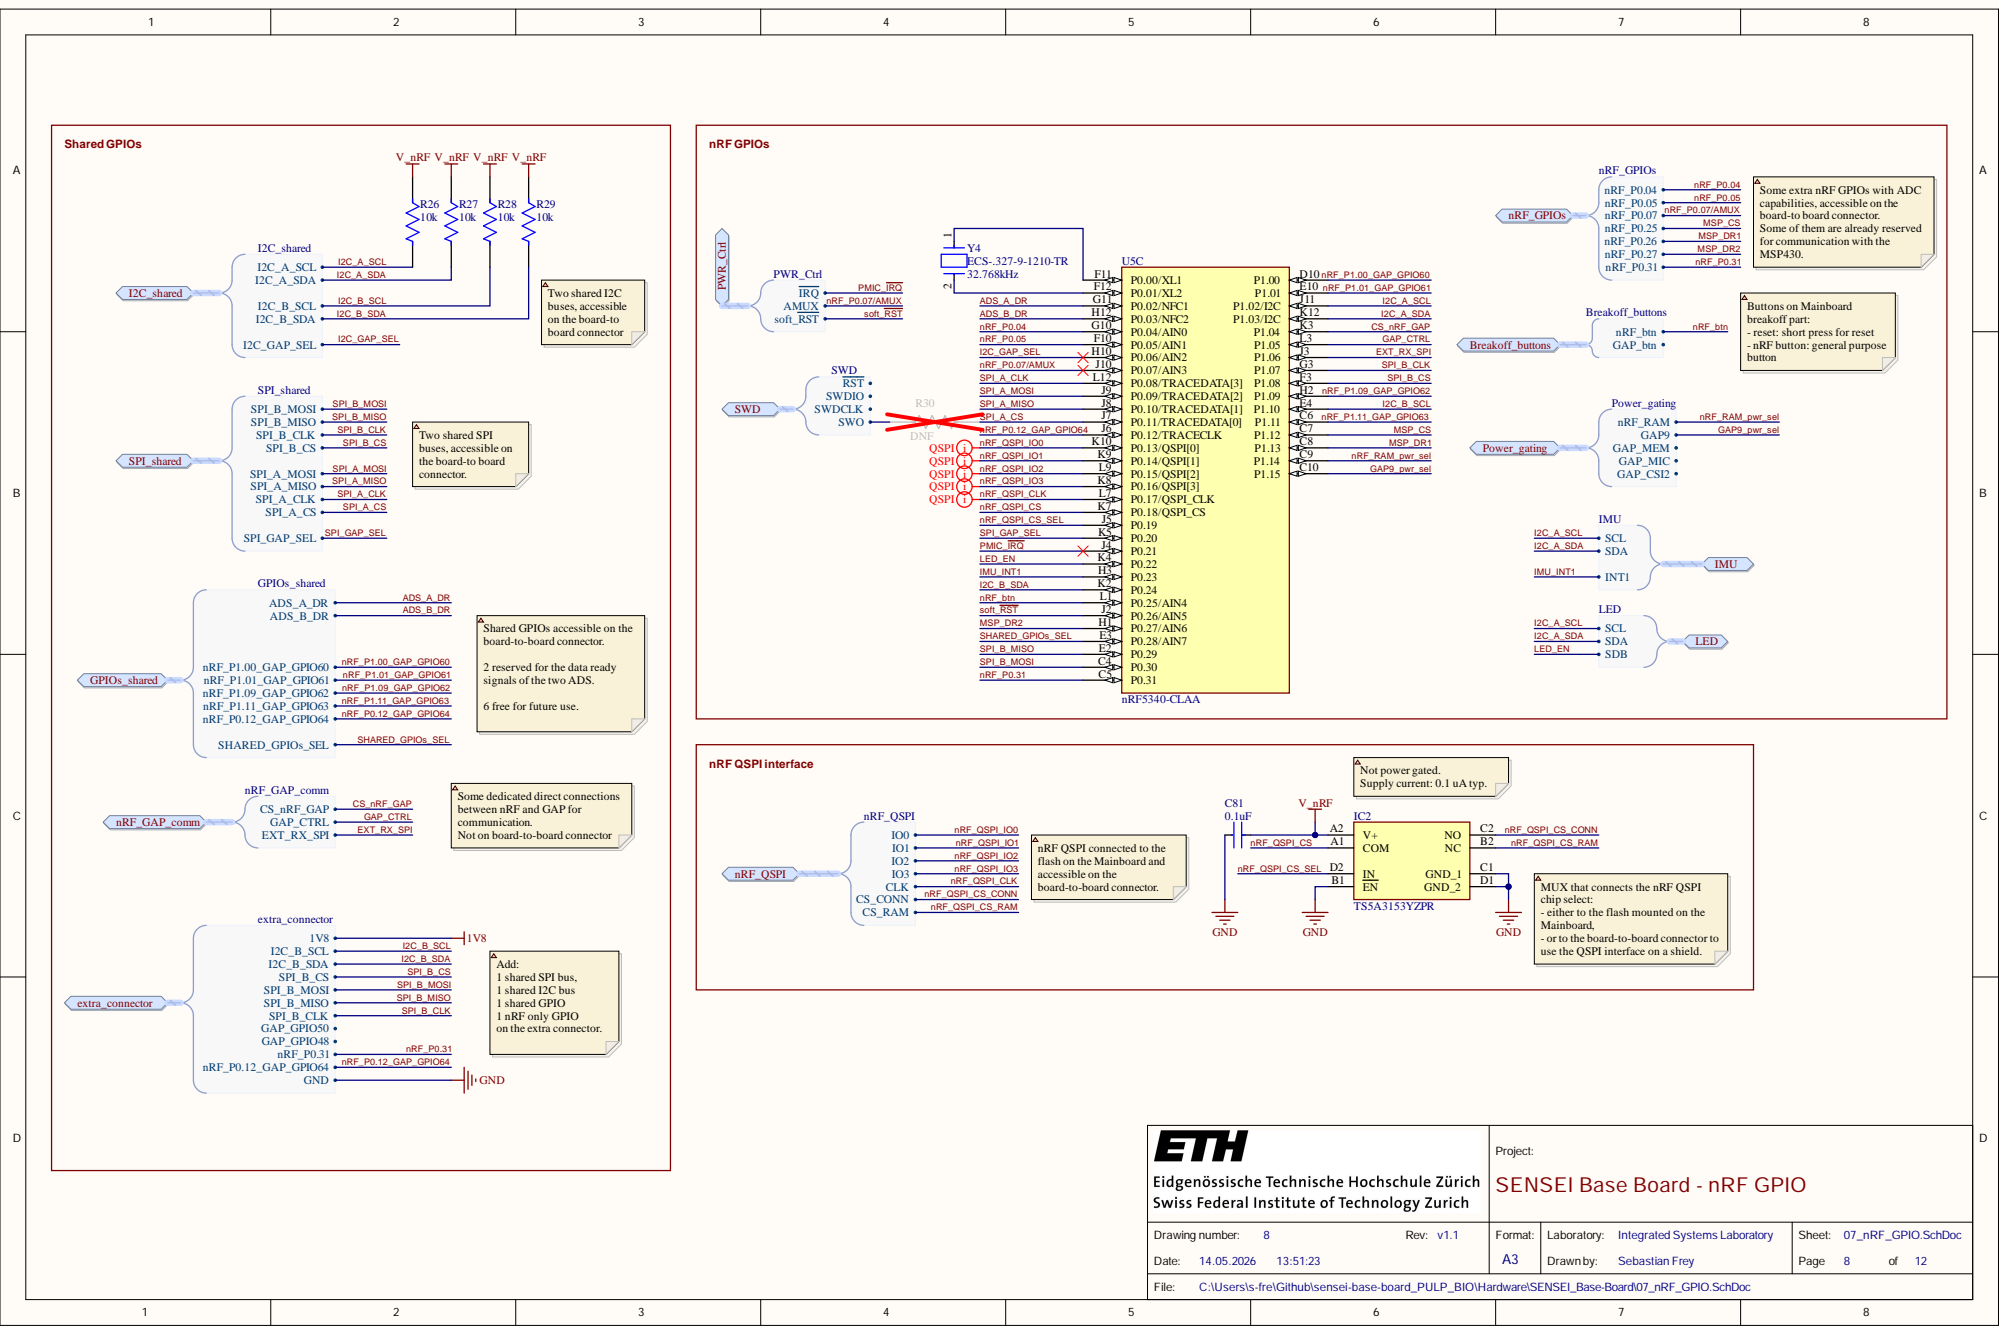
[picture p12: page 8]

Some extra nRF GPIOs with ADC
capabilities, accessible on the
board-to board connector.
Some of them are already reserved
for communication with the
MSP430.

Two shared I2C
buses, accessible
on the board-to
board connector

Buttons on Mainboard
breakoff part:
- reset: short press for reset
- nRF button: general purpose
button

Two shared SPI
buses, accessible on
the board-to board
connector.

Shared GPIOs accessible on the
board-to-board connector.

2 reserved for the data ready
signals of the two ADS.

6 free for future use.

Not power gated.
Supply current: 0.1 uA typ.

Some dedicated direct connections
between nRF and GAP for
communication.
Not on board-to-board connector

nRF QSPI connected to the
flash on the Mainboard and
accessible on the

MUX that connects the nRF QSPI
chip select:
- either to the flash mounted on the
Mainboard,
- or to the board-to-board connector to
use the QSPI interface on a shield.

Add:
1 shared SPI bus,
1 shared I2C bus
1 shared GPIO
1 nRF only GPIO
on the extra connector.

Project: SENSEI Base Board - nRF GPIO

07_nRF_GPIO.SchDoc Page 8 of 12

C:\Users\s-fre\Github\sensei-base-board_PULP_BIO\Hardware\SENSEI_Base-Board\07_nRF_GPIO.SchDoc

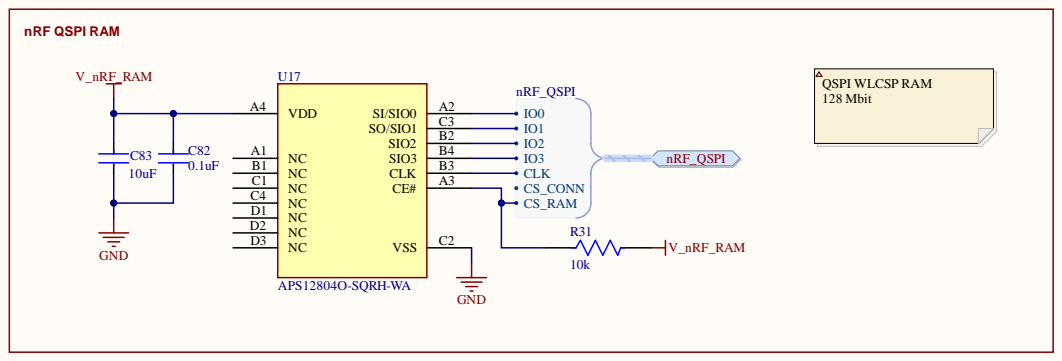
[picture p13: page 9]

Project: SENSEI Base Board - nRF RAM

08_nRF_RAM.SchDoc Page 9 of 12
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

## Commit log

2025-03-10 Initial push
    [00_POWER.SchDoc, 01_GAP_POWER.SchDoc, 02_GAP_JTAG_XTALs.SchDoc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]
2025-11-27 Layout adjustmets - antenna trace reroute, component spacing, mounting holes, nrf debug connector
    [00_POWER.SchDoc, 01_GAP_POWER.SchDoc, 03_GAP_MEM.SchDoc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]
2025-11-27 small adjustments
    [SENSEI_Base-Board.PcbDoc]
2026-05-14 Cleanup for release 1.1
    [00_POWER.SchDoc, 01_GAP_POWER.SchDoc, 02_GAP_JTAG_XTALs.SchDoc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]
